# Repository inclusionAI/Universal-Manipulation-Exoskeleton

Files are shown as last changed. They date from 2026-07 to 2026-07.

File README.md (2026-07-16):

<h1> Universal Manipulation Exoskeleton: Learning Compliant Whole-body Policies with Real-time Torque Feedback</h1>
<div align="center">

[Litian Liang](https://www.litianliang.org/)$^{1,\ast}$, [Jingxi Xu](https://jxu.ai/)$^{1,2,\ast}$, [Xinda Qi](https://www.linkedin.com/in/xinda-qi-42467316a)$^{1}$, [Yujun Cai](https://vanoracai.github.io/)$^{1}$, [Houzhu Ding](https://www.linkedin.com/in/houzhuding/)$^{1}$, [Luqi Wang](luqi.w@antgroup.com)$^{1}$, <br>[Zhixin Sun](https://www.linkedin.com/in/zhixin-sun-867335292/)$^{1}$, [Jyh-Herng Chow](https://www.linkedin.com/in/jyh-herng-chow-5831103/)$^{1}$, [Ming Yang](https://users.ece.northwestern.edu/~mya671/)$^{1}$, [Mark Cutkosky](https://me.stanford.edu/people/mark-cutkosky)$^{2}$

$^1$ Ant Group, $^2$ Stanford University<br> 
$^{\ast}$ Equal Contribution

[Website](https://ume-exo.github.io/) | [Paper](https://arxiv.org/pdf/2606.14218) | [Video](https://youtu.be/1x9Pnb9bv7M?si=n2_0ytXx5yQv7l2F) | [X](https://x.com/litian_liang/status/2066541466286215570)



</div>

Universal Manipulation Exoskeleton (UME) is an upper-limb exoskeleton system that provides real-time haptic torque feedback during real robot teleoperation. UME also provide a simple framework to transfer human teleoperation data to autonomous robot policies.

If you find this codebase useful, consider citing:

```bibtex
@article{liang2026universal,
  title={Universal Manipulation Exoskeleton: Learning Compliant Whole-body Policies with Real-time Torque Feedback},
  author={Liang, Litian and Xu, Jingxi and Qi, Xinda and Cai, Yujun and Ding, Houzhu and Wang, Luqi and Sun, Zhixin and Chow, Jyh-Herng and Yang, Ming and Cutkosky, Mark},
  journal={arXiv preprint arXiv:2606.14218},
  year={2026}
}
```

If you have any questions, please contact [Litian Liang](https://www.litianliang.org/) at `l6liang [at] ucsd [dot] edu` or [Jingxi Xu](https://jxu.ai/) at `jxu [at] cs [dot] columbia [dot] edu`.

**Table of Contents**

If you want to start reproducing the hardware and software, you should [get started here](ume/docs/00_starter.md).

 - 🏃‍♀️ [Getting Started](ume/docs/00_starter.md)
 - 🦾 [Universal Manipulation Exoskeleton](ume/docs/01_hardware.md)
   - 🛠️ [Hardware Guide](ume/docs/01_hardware.md)
   - 💻 [Software Guide](ume/docs/02_software.md)
   - 📷 [Data Collection](ume/docs/02_software.md#data-collection)
 - 🤖 [Model Training and Evaluation](ume/docs/02_software.md#model-training)
   - 🚂 [Training](ume/docs/02_software.md#model-training)
   - 📊 [Evaluation](ume/docs/02_software.md#model-evaluation-on-real-robot)
 - 🌍 [Real World Deployment](ume/docs/02_software.md#model-evaluation-on-real-robot)

# Acknowledgements
This work is supported by Ant Group.

We would like to thank Hao Li and Tian-Ao (Teo) Ren from the Stanford BDML Lab for insightful discussions on the mechanical design of UME. We are grateful to Yifan Hou, Zhanyi Sun, and Professor Shuran Song from the Stanford REAL Lab for valuable discussions on autonomous robot experimental design and future applications. We are grateful to Mikael Jorda for feedback on the design of the retargeting algorithm.

We would also like to thank Xiangpeng Miao from Damiao Technology for actuator suggestions and support, Heng Le from X-ARM for assistance with the robotic arms, and Haoxing Guo from Hexfellow Robotics for support with the power caster module.

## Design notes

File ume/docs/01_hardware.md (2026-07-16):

# Hardware Guide

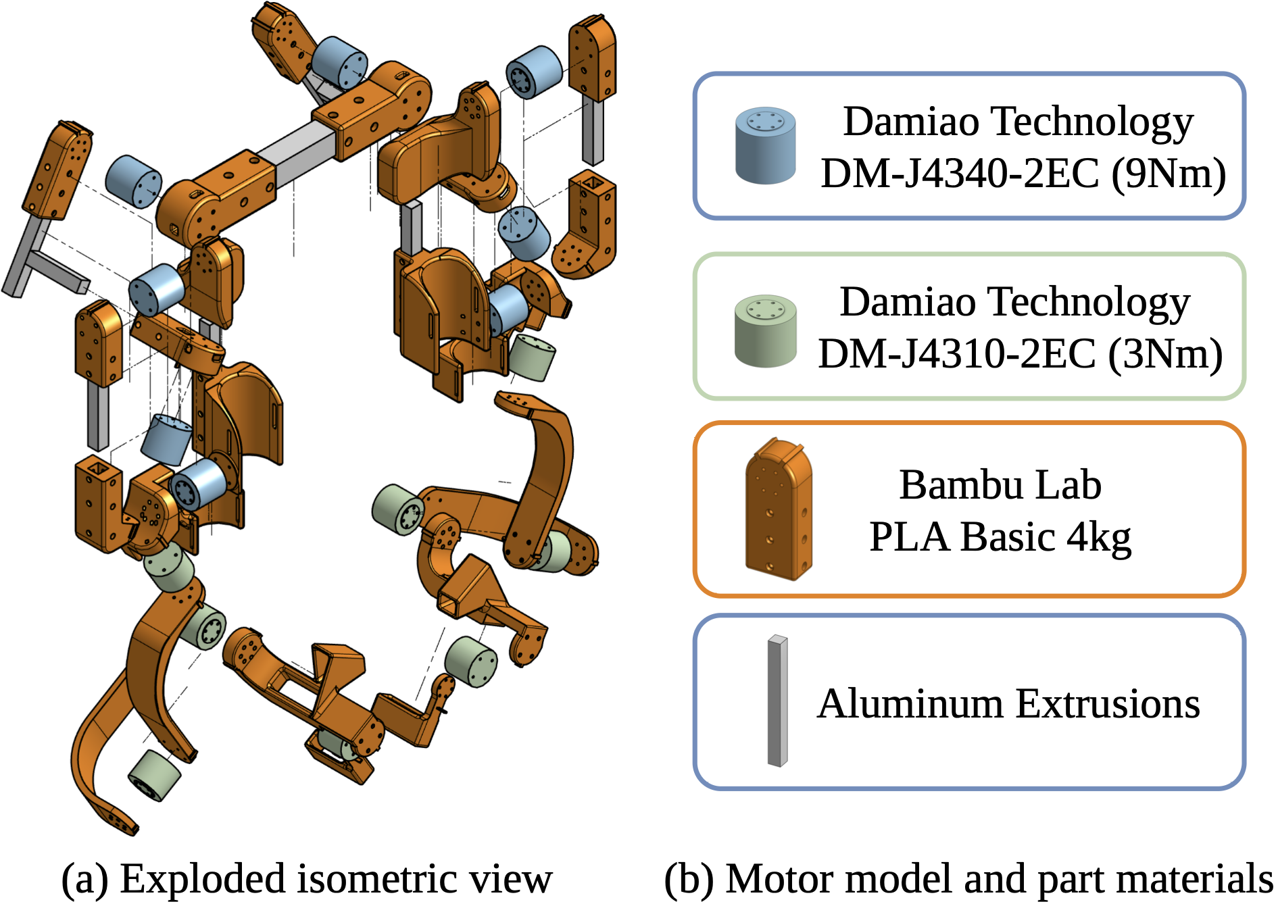
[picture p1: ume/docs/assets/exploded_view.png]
exploded view


## 1. Exoskeleton Parts Preparation:
1. Get the aluminum extrusions, screws, and actuators ready (checkout [paper](https://arxiv.org/pdf/2606.14218) Appendix E.2 for details)
2. Print all the orange parts in PLA basic, checkout [robot model](../robot/ume/v6_imu/models/robot.xml) for part 3D STL files

## 2. Exoskeleton Damiao Actuator Configuration:
Note: For each actuator, it is easier to configure them before installing, although you can still do that through the hole I left for the UART port on the actuator. Here are the steps you need to do to reproduce UME:
1. Download and open [DM tool](https://github.com/dmBots/motor-debugging-tool/tree/7406da26cb56b4c024039f85fde6f7a086ac7e11/Windows/x86_64)
2. Connect the actuator UART port to the [DM UART to USB-C adapter](https://item.taobao.com/item.htm?id=639679565187), then to your PC. Set your DC power supply to 24V and get ready to power on the actuator.

3. Click "open serial port" （打开串口）, it'll turn green and change to "close serial port"（关闭串口）.

4. Power on the actuator. If this status report does not show up, it means the connection is not successful. Try another USB-C cable.
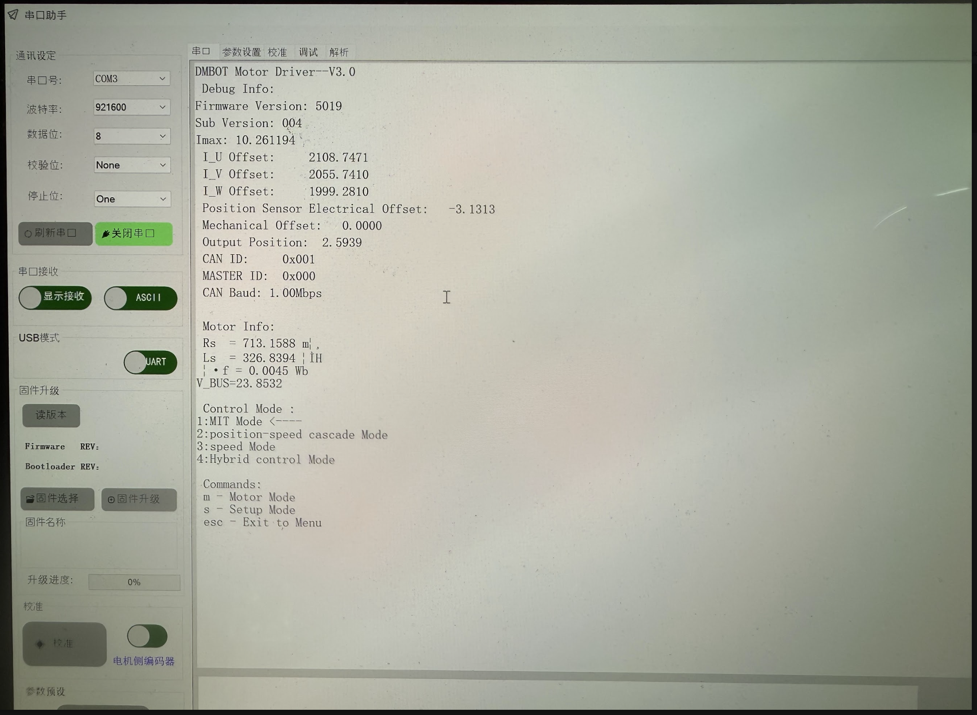
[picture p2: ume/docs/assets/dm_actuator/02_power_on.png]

5. Click Parameter settings（参数设置） in the top selection bar, then click Read parameters（读参数）.
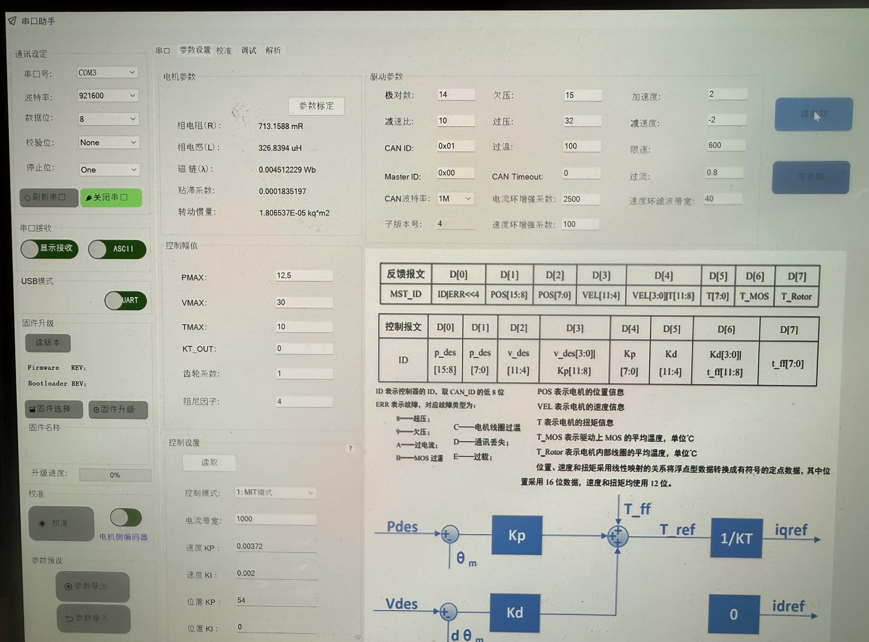
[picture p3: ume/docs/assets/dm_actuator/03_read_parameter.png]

6. For the ith actuator on each arm (from shoulder to gripper 1-8), lets use an example of the shoulder actuator (the 1st)
   1. Set CAN-ID to 0x01 (0x0i for ith)
   2. Set master ID to 0x11 (0x1i for ith)
   3. Click "write parameter"（写参数）. You should see a window pop up saying "parameter write successful"（参数写入成功）
   
7. Go back to the "serial port"（串口） tab in the top selection bar. Set communication frequency to 5Mbps.
   1. Type "s" in the command window below and click send
   2. Type "FCB9" to set the comm frequency to 5Mbps
   3. Power cycle the actuator, you should see a status report that has all the above changes applied. (CAN ID, MASTER ID, CAN BAUD)
   
8. You have successfully configured this actuator. Now repeat the above steps for all the right arm (1-8) and left arm (1-8) actuators.

## 3. Exoskeleton Fabrication & Assembly:

3D printing files checkout: [ume_step folder](../robot/ume/ume_step). Also, please feel free to change the arm length to fit your arm better!

3D printing notes:
1. Use Bambu PLA basic material
2. Slice with triangular pattern and 20% infill
3. It is recommended to use Orange PLA for better strength

I recommend mounting the shoulder onto the table and start assembling from shoulder to wrist. It is also helpful to follow the exploded view above to assemble the exoskeleton. Here are some tips to help you speed up the assembly process

1. For each actuator, use a screw that is ~5mm longer than the depth of screw hole on the PLA parts.
2. For shoulder J2 actuator, first thread the XT30 2+2 cable from J1 through the 2020 aluminum extrusion, then through the hole on the PLA part, then connnect it to J2. This hides the wire in the slot of aluminum extrusion.
3. For other actuators, first assemble and connect the wires. Then rotate the joint to the limit of human range of motion to find the minimum length of wire that needs to be free floating, then tape the wire down to anywhere on the exoskeleton that does not block your movements.
4. Mount the yahboom imu anywhere on the back of exoskeleton with x up y left z forward configuration.

Great! Now you have successfully assembled it. Let's zero all the actuators so they are consistent with software robot model.

## 4. Exoskeleton Actuator Zeroing

1. Print the Zeroing key (a block with a 5mm x 2.5mm x 100mm slot)
2. Find the bump before and after the actuator. Align them and hold them together with the key.
3. Run `ume/robot/ume/v6_bimanual/motor_chain_test.py` but change the `motor_ids` and `motor_types` to the one that you are working on. Then uncomment the `damiao_chain.set_zero()` line and run the code.
4. When running the code, you should see the actuator turn green. And the program outputs 0 for position reading.
5. Now you successfully zeroed this joint. Now repeat for all joints.
6. After you finished all the joints. Check your zeroing with `ume/robot/ume/v6_imu/real_teleop_sim.py`. For safety, make sure to zero out the torque command (change the torque multiplier before the tau_ff_R to 0 here `data_R = ume_R.mit_control(kp=q_zeros, kd=q_zeros, q=q_zeros, dq=q_zeros, tau=1 * tau_ff_R)`) for both arms.

Great! If everything look good, `ume/robot/ume/v6_imu/real_teleop_sim.py` should give correct gravity compensation. Try move the exoskeleton with your hand!

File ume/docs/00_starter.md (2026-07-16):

# Getting Started

Recomended steps to reproduce UME:
1. Clone repo
2. Follow [hardware](01_hardware.md) guide for UME and mobile manipulator assembly
3. Follow [software](02_software.md) guide to make sure all connections are made correctly

After that you should have a working UME!

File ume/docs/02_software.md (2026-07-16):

# Software

Install conda envs using the yaml config files
* `ume/conda_envs/ume_redis.yaml` (robot, teleoperation, inference)
* `ume/conda_envs/ume_torch.yaml` (training, inference)

## 1. Setup

Setup python environment variable.
```
export PYTHONPATH=.
```

### 1.1 Connect to Exoskeleton Yahboom IMU
To use Yahboom IMU, first add yourself to the dialout group to enable serial reading. (I recommend using arduino ide or vscode serial monitor to monitor serial device output)
```
bash ume/robot/ybimu/add_dialout_group.sh
```
If you still can't see serial output, then try disable brltty and reboot.

```
bash ume/robot/ybimu/disable_brltty.sh
```

Now you should be able to see serial output. And run the Yahboom official IMU reader code.
```
conda activate ume_redis
python ume/robot/ybimu/YbImuSerialLib.py
```

### 1.2 Connect to Hexfellow PCW-25 and Damiao Motors
Enable can, (make sure mobile base is on CAN0&1, arm on CAN2&3, exo on CAN4&5)
```
bash ume/robot/mobile_openarm/enable_can.sh
```
You can run this script to check which device is connected to which CAN. This script will make the damiao motors led light go green.
```
python ume/robot/ume/v6_bimanual/motor_chain_test.py
```

### 1.3 Hexfellow PCW-25 Robot Wheel Zeroing
1. connect a xbox gamepad to the computer
2. run `ume/robot/mobile_openarm/hexfellow_base_xbox_teleop.py` to start teleoperating the mobile base
3. adjust `rev_offset` in the `get_actual_position_rad` of `ume/robot/mobile_openarm/ hexfellow_base_imu_teleop_redis.py` base on your wheel mounting orientation
4. adjust `rev_offset` until the robot moves in the correct orientation (pitch corresponds to robot local frame x direction, roll is y, and yaw is theta)

## 2. Gravity compensation Demo
To help make sure UME is reproduced correctly, you can run the gravity compensation demo to check if the torque value is correct. 

**First time reproduction note**: it is safer to enable the mujoco visualization window, and multiply 0.5 to the gravity compensation torque.
```
python ume/robot/ume/v6_imu/real_teleop_sim.py
```

## 3. Teleop OpenArm

Run the arm teleoperation demo. This helps you make sure both openarm and UME are configured correctly.
* press `b` to slowly move the arm to the desired position
* press ` to engage torque-feedback teleoperation
```
process-compose -f ume/robot/ume/v6_imu/teleop_openarm.yaml
```

Run the mobile teleoperation demo. Tilt your body to control the mobile base, same keys as above to start the arm teleoperation.
```
process-compose -f ume/robot/ume/v6_imu/teleop_openarm_mobile.yaml
```

Now UME and Hexfellow OpenArm mobile manipulator are all working properly. Let's collect some data with it.

# Data Collection

Run the data collection script.
```
process-compose -f ume/robot/mobile_openarm/collect_data.yaml
```
You should see the live camera preview show up, and a window of a pure green image to indicate recording is not started (red if recording).
* press `b` to slowly move the arm to the desired position
* press ` to engage torque-feedback teleoperation
* press `u` to start recording
* press `q` to stop recording

data collected should be in the `data` folder in the format of
```
data
|--collecting
   |--YYYY_MM_DD_HH_MM_SS_TIMEZONE
      |--low_dim_npys
      |--camera_head.mp4
      |--camera_wrist_left.mp4
      |--camera_wrist_right.mp4
```

# Model Training
Train a UME model:
```
python ume/learning/mobile_openarm_ume/act_train_ume.py
```
Train No-Torque baseline model:
```
python ume/learning/mobile_openarm_no_torque/act_train_no_torque.py
```
Train UMI baseline model:
```
python ume/learning/mobile_openarm_umi/act_train_umi.py
```

# Model Evaluation on Real Robot

## 1. Setup
1. setup model ckpt path at `ume/learning/mobile_openarm_ume/model_inference_worker.py`
2. setup initial arm configuration path at `ume/learning/mobile_openarm/eval_openarm_controller.py`

## 2. Eval
Evaluate a UME model:
```
process-compose -f ume/learning/mobile_openarm_ume/eval_mobile_openarm.yaml
```
You can use similar commands to evaluate No-Torque and UMI baseline models.

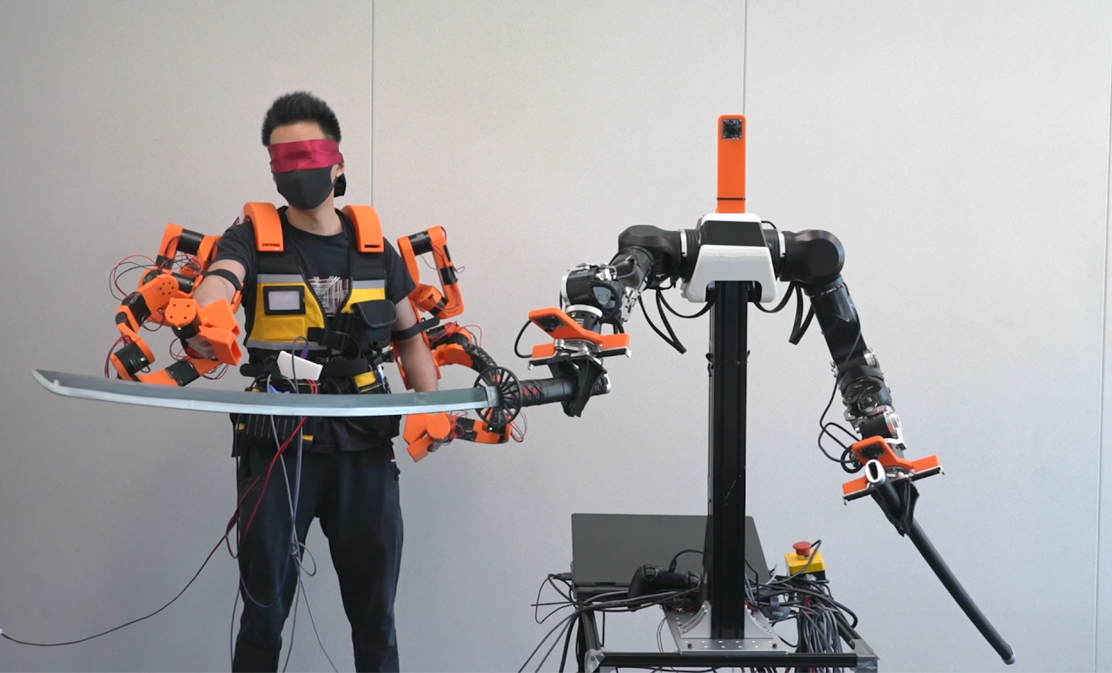
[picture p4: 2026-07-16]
ume/docs/assets/unsheathe_final.png

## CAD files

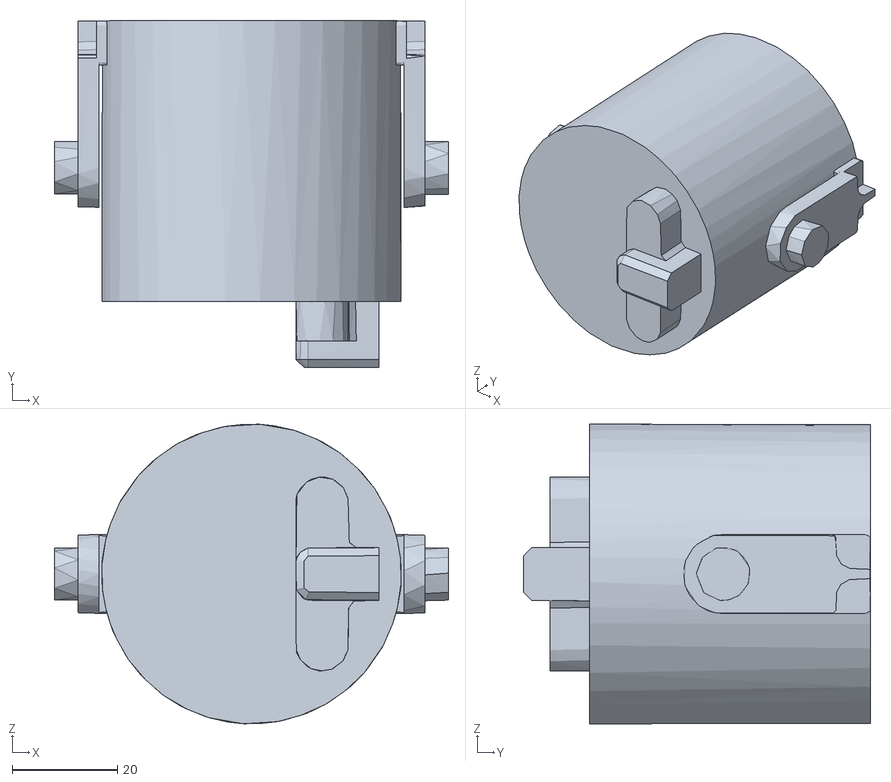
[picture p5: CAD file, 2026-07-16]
ume/robot/openarm1/models/meshes/collision/arm/link6.stl
75.0 x 66.0 x 57.0

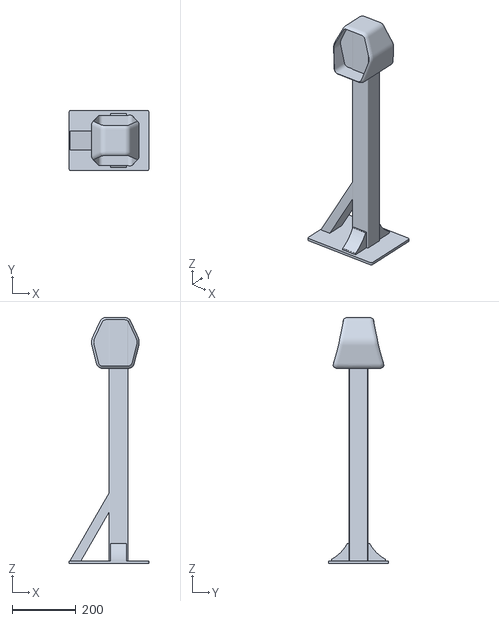
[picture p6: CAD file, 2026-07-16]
ume/robot/openarm1/models/meshes/collision/body/body_link0.stl
250.0 x 190.0 x 773.0

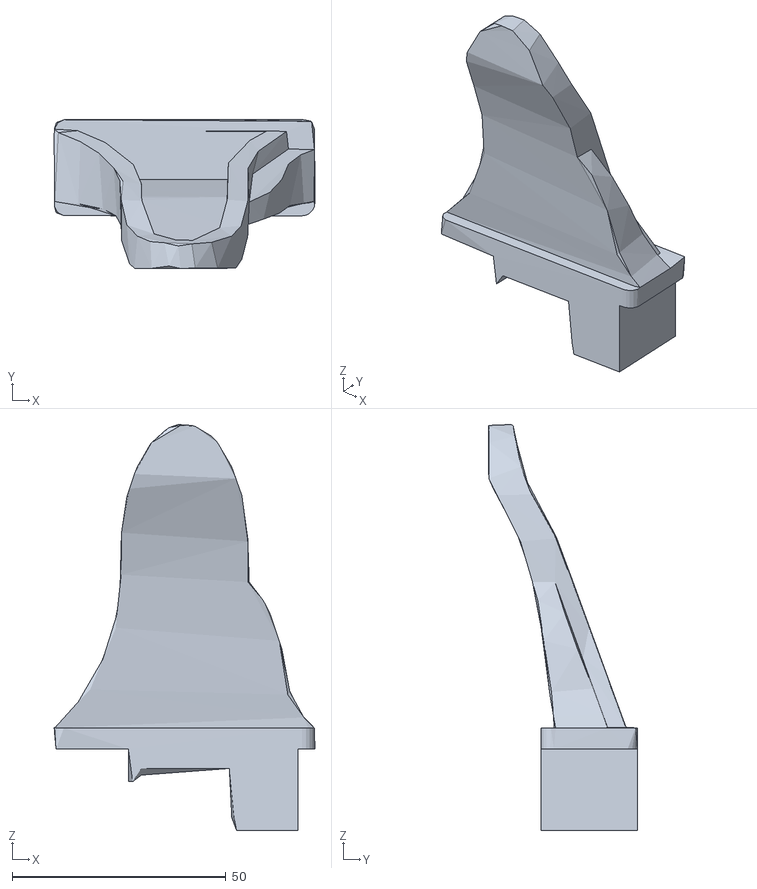
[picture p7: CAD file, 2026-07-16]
ume/robot/openarm1/models/meshes/collision/gripper/finger.stl
61.0 x 34.8 x 94.9

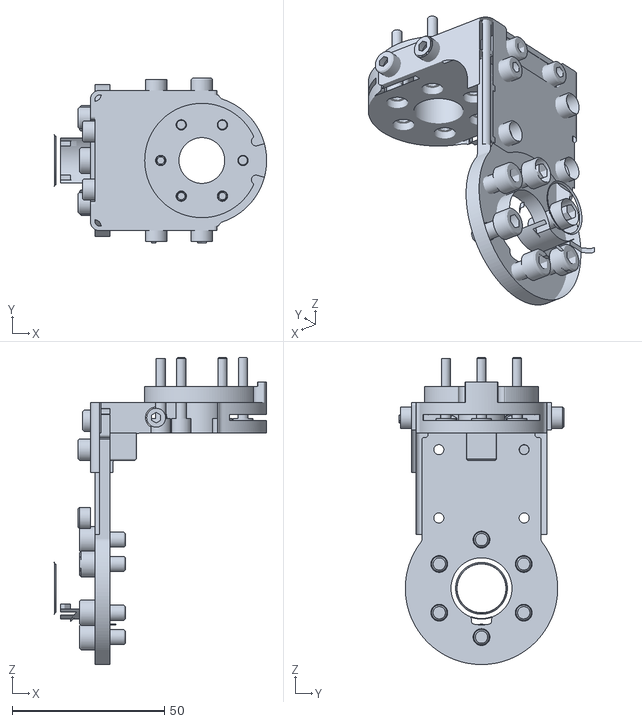
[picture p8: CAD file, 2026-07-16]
ume/robot/openarm1/models/meshes/visual/arm/link2_1.obj
69.7 x 54.0 x 100.7

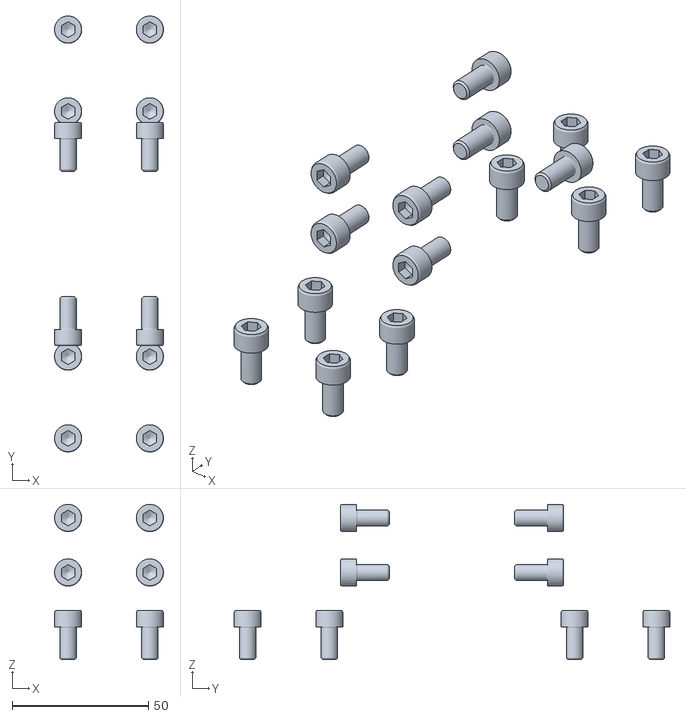
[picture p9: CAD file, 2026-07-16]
ume/robot/openarm1/models/meshes/visual/body/body_link0_2.obj
40.0 x 160.0 x 57.0

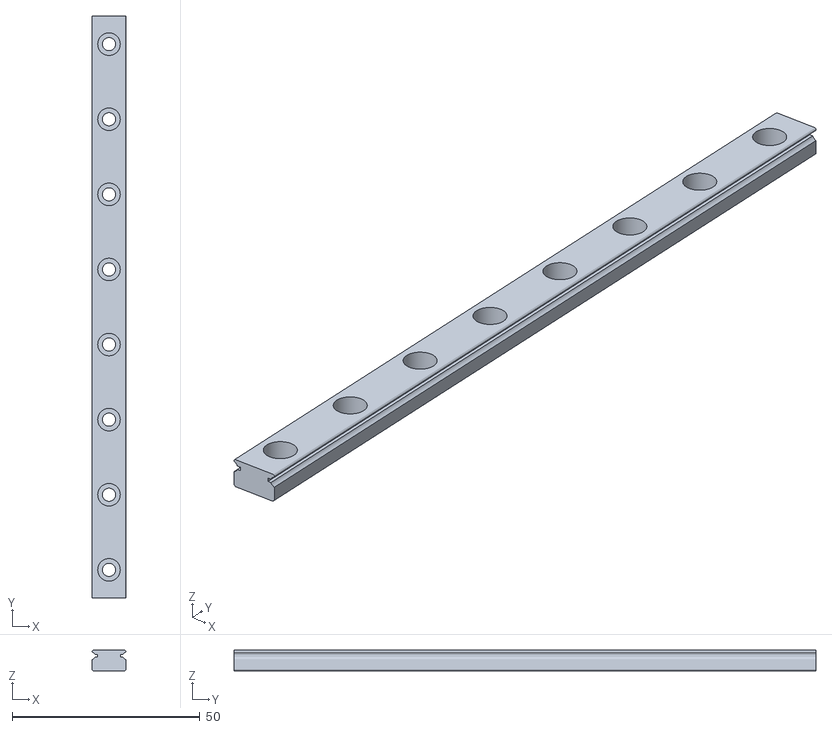
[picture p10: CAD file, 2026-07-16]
ume/robot/openarm1/models/meshes/visual/gripper/hand_0.obj
9.00 x 155.0 x 5.50

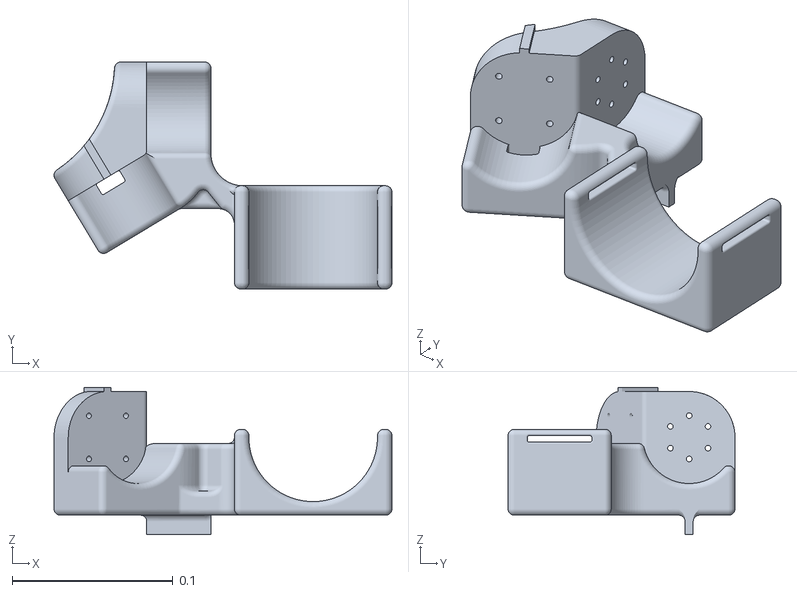
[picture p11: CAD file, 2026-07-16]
ume/robot/ume/v6_imu/models/assets/v6_j4_j5_r.stl
0.21 x 0.141 x 0.0915

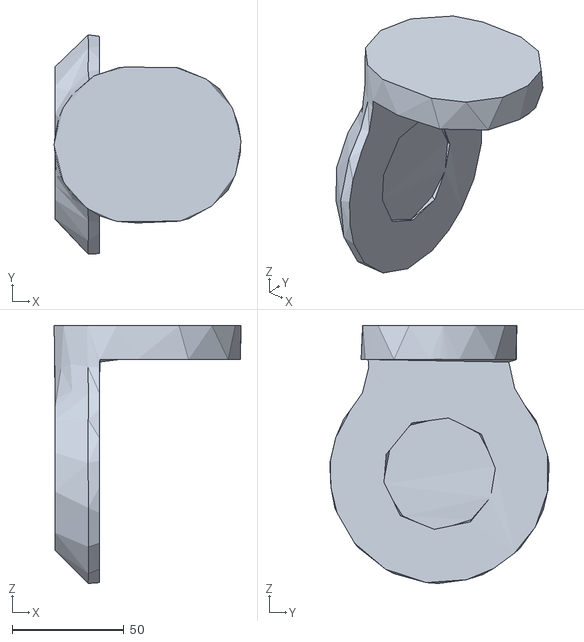
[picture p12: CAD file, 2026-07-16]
ume/robot/openarm1/models/meshes/collision/arm/link2.stl
83.7 x 98.3 x 115.6

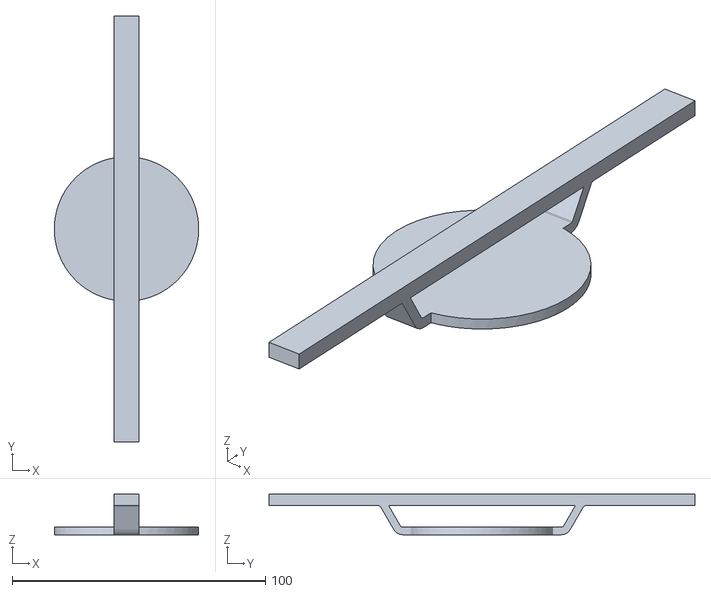
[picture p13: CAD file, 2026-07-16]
ume/robot/openarm1/models/meshes/collision/gripper/hand.stl
57.0 x 168.1 x 16.0

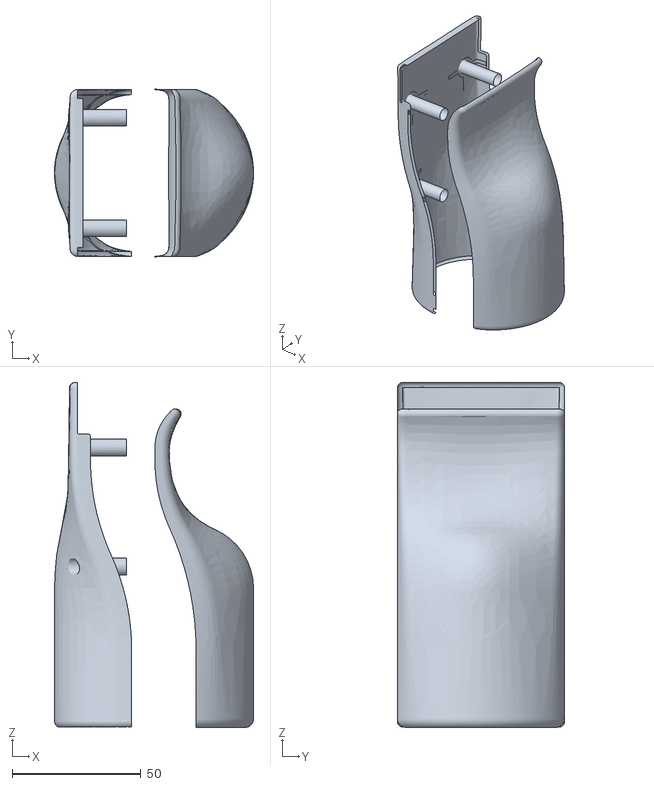
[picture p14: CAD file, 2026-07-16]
ume/robot/openarm1/models/meshes/visual/arm/link3_1.obj
77.3 x 65.0 x 134.0

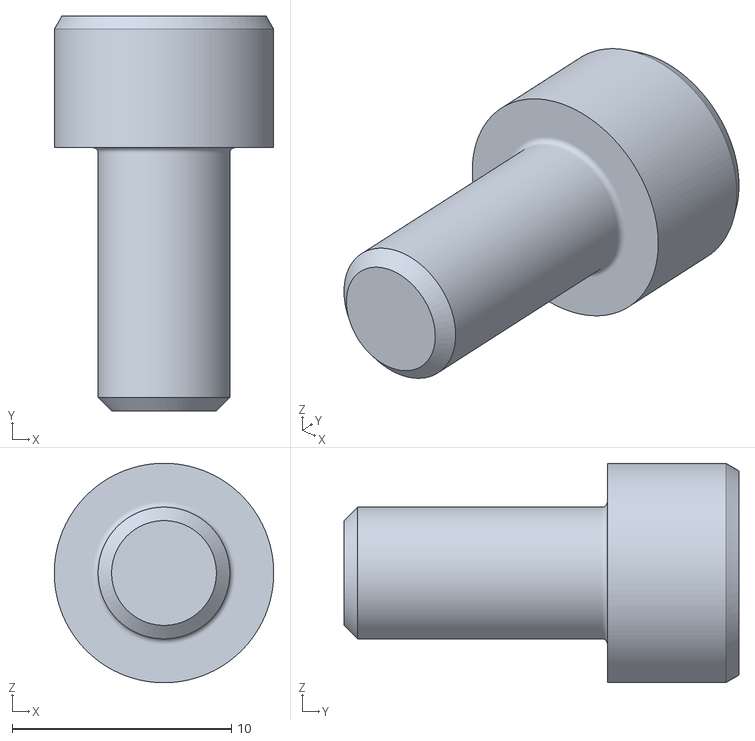
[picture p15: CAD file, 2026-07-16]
ume/robot/openarm1/models/meshes/visual/body/body_link0_0.obj
10.0 x 18.0 x 10.00

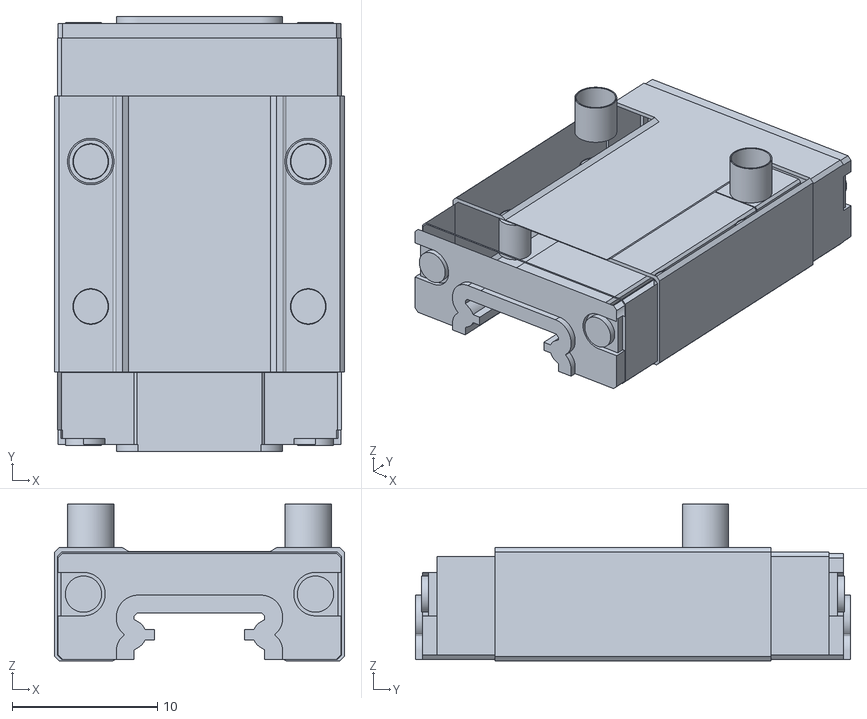
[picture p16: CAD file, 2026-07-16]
ume/robot/openarm1/models/meshes/visual/gripper/finger_0.obj
20.0 x 30.0 x 10.8

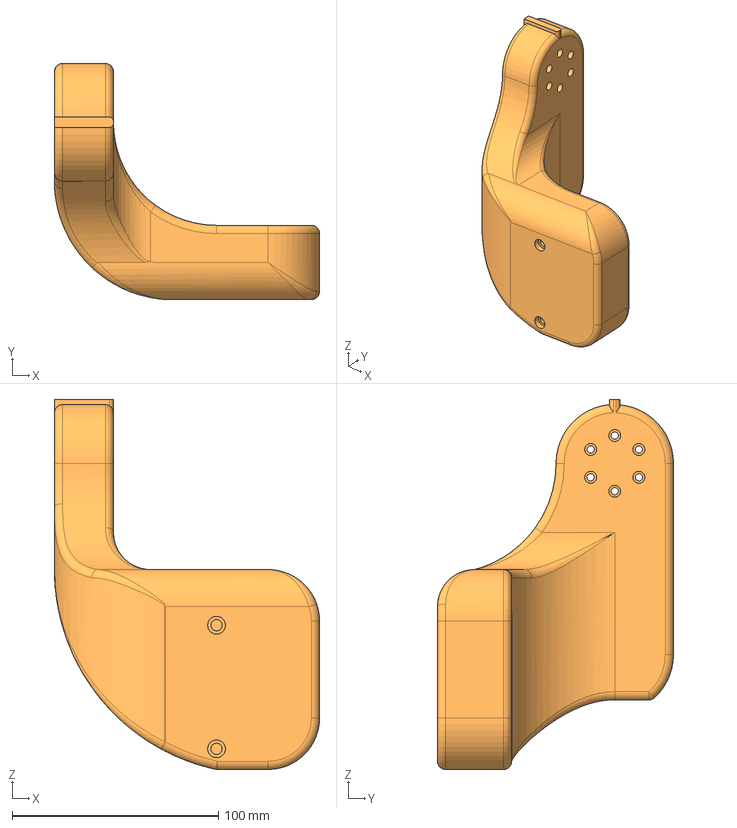
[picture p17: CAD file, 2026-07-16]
ume/robot/ume/ume_step/ume_v6_bimanual - v6_J3_2020_L.step
128.7 x 114.5 x 179.5 mm

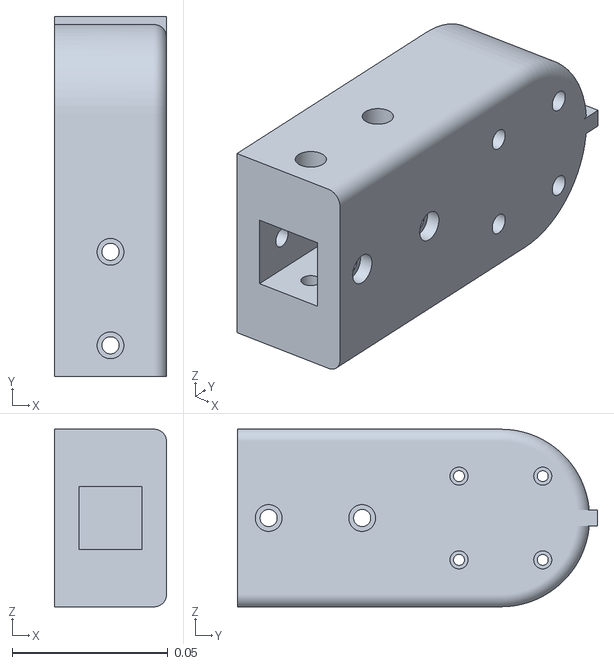
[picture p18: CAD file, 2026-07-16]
ume/robot/ume/v6_bimanual/models/assets/v6_j2_20.stl
0.036 x 0.116 x 0.057

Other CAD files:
ume/robot/ume/v6_imu/models/assets/4040_ybimu.stl
ume/robot/openarm1/models/meshes/collision/arm/link0.stl
ume/robot/openarm1/models/meshes/visual/arm/link5_0.obj
ume/robot/openarm1/models/meshes/visual/body/body_link0_1.obj
ume/robot/openarm1/models/meshes/collision/arm/link1.stl
ume/robot/openarm1/models/meshes/collision/arm/link3.stl
ume/robot/openarm1/models/meshes/collision/arm/link4.stl
ume/robot/openarm1/models/meshes/collision/arm/link5.stl
ume/robot/openarm1/models/meshes/collision/arm/link7.stl
ume/robot/openarm1/models/meshes/visual/arm/link0_0.obj
ume/robot/openarm1/models/meshes/visual/arm/link0_1.obj
ume/robot/openarm1/models/meshes/visual/arm/link1_0.obj
ume/robot/openarm1/models/meshes/visual/arm/link1_1.obj
ume/robot/openarm1/models/meshes/visual/arm/link1_2.obj
ume/robot/openarm1/models/meshes/visual/arm/link1_3.obj
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

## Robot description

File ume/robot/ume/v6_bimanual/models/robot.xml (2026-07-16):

<?xml version="1.0" ?>
<mujoco model="models">
  <compiler angle="radian" meshdir="assets" autolimits="true"/>
  <default>
    <default class="models">
      <joint frictionloss="0.1" armature="0.005"/>
      <position kp="50" dampratio="1"/>
      <default class="visual">
        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
      </default>
      <default class="collision">
        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
      </default>
    </default>
  </default>
  <worldbody>
    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
    <body name="v5_4040_j1" pos="0 0 0" quat="1 0 0 0" childclass="models">
      <inertial pos="-0.00725532 0.0615 -0" mass="1.044" fullinertia="0.0381441 0.000626549 0.0381676 -0 -0 6e-11"/>
      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
      <body name="v6_j1_20" pos="-0.0383 -0.1385 0" quat="0.183013 0.683013 -0.183013 -0.683013">
        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
        <joint axis="0 0 1" name="RJ1" type="hinge"/>
        <inertial pos="0.150386 -5.99e-10 -0.0862657" mass="0.64749" fullinertia="0.0032465 0.00514141 0.00215547 6e-12 0.00180143 1.8e-11"/>
        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
        <body name="v6_20_j3" pos="0.2065 -0 -0.139098" quat="0.5 0.5 0.5 0.5">
          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
          <joint axis="0 0 1" name="RJ2" type="hinge"/>
          <inertial pos="0.0816108 2.273e-09 -0.108365" mass="0.6629" fullinertia="0.00347714 0.00399968 0.000810527 1.64e-10 0.00105864 -1.66e-10"/>
          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
          <body name="v6_j3_2020_r" pos="0.0680103 -0 -0.175034" quat="0.353553 0.612372 -0.612372 -0.353553">
            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
            <joint axis="0 0 1" name="RJ3" type="hinge"/>
            <inertial pos="-0.0212538 0.197218 0.0388781" mass="0.86248" fullinertia="0.00735386 0.00260883 0.00681043 -0.00104227 0.000890554 0.000819778"/>
            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
            <body name="v6_j4_j5_r" pos="0.00787981 0.26 -0.025968" quat="0 0.707107 -0.707107 -0">
              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
              <joint axis="0 0 1" name="RJ4" type="hinge"/>
              <inertial pos="-0.054697 0.00944171 -0.00245461" mass="0.49139" fullinertia="0.00105657 0.00119188 0.000538644 -2.97344e-05 -0.000120659 0.000177465"/>
              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
              <body name="v6_wrist_j5_j6" pos="-0.0825226 -0 0.000785249" quat="0 -0.870373 0 0.492393">
                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
                <joint axis="0 0 1" name="RJ5" type="hinge"/>
                <inertial pos="-0.145145 7.46224e-05 0.168843" mass="0.4484" fullinertia="0.00261478 0.00340573 0.00098092 -2.29433e-06 0.00132169 3.71339e-06"/>
                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
                <body name="v5_wrist_j6_j7" pos="-0.1919 0 0.212" quat="0 -0.707107 -0 0.707107">
                  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
                  <joint axis="0 0 1" name="RJ6" type="hinge"/>
                  <inertial pos="-0 0.0975631 -0.161926" mass="0.407" fullinertia="0.00180585 0.00164708 0.000326757 0 -0 0.000247612"/>
                  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
                  <body name="v5_wrist_j7_leader_gripper_r" pos="-0 0.0751 -0.191" quat="0.5 0.5 -0.5 0.5">
                    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
                    <joint axis="0 0 1" name="RJ7" type="hinge"/>
                    <inertial pos="-0.00205487 0.0647313 0.154012" mass="0.4573" fullinertia="0.00200291 0.00193779 0.000443531 -3.45159e-05 2.74273e-06 -0.000439089"/>
                    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
                    <body name="v5_j8_4finger" pos="0 0.075 0.1641" quat="0 -0.707107 -0.707107 -0">
                      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
                      <joint axis="0 0 1" name="RJ8" type="hinge"/>
                      <inertial pos="0.0582262 -2.729e-09 0.031412" mass="0.0384" fullinertia="3.92746e-05 6.14789e-05 2.96973e-05 -1e-12 -1.19931e-05 2e-12"/>
                      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
                    </body>
                  </body>
                </body>
              </body>
            </body>
          </body>
        </body>
      </body>
      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
      <body name="dm_j4340_2ec" pos="-0.0383 0.2615 -0" quat="0.183013 -0.683013 -0.183013 0.683013">
        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
        <joint axis="0 0 1" name="LJ1" type="hinge"/>
        <inertial pos="0.150386 -5.99e-10 -0.0862657" mass="0.64749" fullinertia="0.0032465 0.00514141 0.00215547 6e-12 0.00180143 1.8e-11"/>
        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
        <body name="dm_j4340_2ec_2" pos="0.2065 0 -0.139098" quat="0.5 -0.5 0.5 -0.5">
          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
          <joint axis="0 0 1" name="LJ2" type="hinge"/>
          <inertial pos="0.0816108 2.273e-09 -0.108365" mass="0.6629" fullinertia="0.00347714 0.00399968 0.000810527 1.64e-10 0.00105864 -1.66e-10"/>
          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
          <body name="v6_j3_2020_l" pos="0.0680103 -0 -0.175034" quat="0.353553 -0.612372 -0.612372 0.353553">
            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
            <joint axis="0 0 1" name="LJ3" type="hinge"/>
            <inertial pos="-0.0211335 -0.197218 0.0388781" mass="0.86248" fullinertia="0.00735383 0.00260882 0.0068104 0.00104226 0.00089055 -0.00081978"/>
            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
            <body name="v6_j4_j5_l" pos="0.008 -0.26 -0.025968" quat="0 0.707107 0.707107 0">
              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
              <joint axis="0 0 1" name="LJ4" type="hinge"/>
              <inertial pos="-0.054697 -0.0094417 -0.00245459" mass="0.49139" fullinertia="0.00105657 0.00119187 0.000538643 2.97343e-05 -0.000120659 -0.000177465"/>
              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
              <body name="v6_wrist_j5_j6_2" pos="-0.0825226 -0 0.000785249" quat="0 -0.870373 0 0.492393">
                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
                <joint axis="0 0 1" name="LJ5" type="hinge"/>
                <inertial pos="-0.145035 -0.000119401 0.168953" mass="0.4484" fullinertia="0.00260463 0.00340197 0.000987304 3.35036e-06 0.00132357 -5.25689e-06"/>
                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
                <body name="v5_wrist_j6_j7_2" pos="-0.1919 -0 0.212" quat="0.707107 0 -0.707107 -0">
                  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
                  <joint axis="0 0 1" name="LJ6" type="hinge"/>
                  <inertial pos="-0 0.0975631 -0.161926" mass="0.407" fullinertia="0.00180585 0.00164708 0.000326757 0 -0 0.000247612"/>
                  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
                  <body name="dm_j4310_2ec" pos="-0 0.0751 -0.191" quat="0.5 0.5 0.5 -0.5">
                    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
                    <joint axis="0 0 1" name="LJ7" type="hinge"/>
                    <inertial pos="0.00205488 0.0647314 0.154012" mass="0.4573" fullinertia="0.00200291 0.00193779 0.000443531 3.45159e-05 -2.7424e-06 -0.000439089"/>
                    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
                    <body name="v5_j8_4finger_2" pos="0 0.075 0.1641" quat="0 -0.707107 -0.707107 -0">
                      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
                      <joint axis="0 0 1" name="LJ8" type="hinge"/>
                      <inertial pos="0.0582262 -2.729e-09 0.031412" mass="0.0384" fullinertia="3.92746e-05 6.14789e-05 2.96973e-05 -1e-12 -1.19931e-05 2e-12"/>
                      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
                    </body>
                  </body>
                </body>
              </body>
            </body>
          </body>
        </body>
      </body>
    </body>
  </worldbody>
  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
  <actuator>
    <position class="models" name="RJ1" joint="RJ1"/>
    <position class="models" name="RJ2" joint="RJ2"/>
    <position class="models" name="RJ3" joint="RJ3"/>
    <position class="models" name="RJ4" joint="RJ4"/>
    <position class="models" name="RJ5" joint="RJ5"/>
    <position class="models" name="RJ6" joint="RJ6"/>
    <position class="models" name="RJ7" joint="RJ7"/>
    <position class="models" name="RJ8" joint="RJ8"/>
    <position class="models" name="LJ1" joint="LJ1"/>
    <position class="models" name="LJ2" joint="LJ2"/>
    <position class="models" name="LJ3" joint="LJ3"/>
    <position class="models" name="LJ4" joint="LJ4"/>
    <position class="models" name="LJ5" joint="LJ5"/>
    <position class="models" name="LJ6" joint="LJ6"/>
    <position class="models" name="LJ7" joint="LJ7"/>
    <position class="models" name="LJ8" joint="LJ8"/>
  </actuator>
  <equality/>
</mujoco>

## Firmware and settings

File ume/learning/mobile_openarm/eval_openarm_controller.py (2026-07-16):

import time

import can
import numpy as np

import typer
from ume.redis_client import RedisClient
from ume.tools.precise_sleep import FrequencyRegulator

from ume.robot.openarm1.solver import OpenArm1Solver
from ume.tools.keycounter import KeystrokeCounter, Key, KeyCode
from ume.tools.pose_interp import get_interp1d
from ume.tools.npy_read_write import save_dict_to_npy, load_dict_from_npy

FOLLOWER_KP = np.array([240.0, 240.0, 240.0, 240.0, 24.0, 31.0, 25.0, 16.0])
FOLLOWER_KD = np.array([3.0, 3.0, 3.0, 3.0, 0.2, 0.2, 0.2, 0.2])

def main(
    redis_host: str = "localhost",
    redis_port: int = 6379,
    follower_left: str = "follower_left",
    follower_right: str = "follower_right",
    frequency_hz: float = 2000,
    initial_arm_state_reference_episode_lowdim_path: str = "data/initial_pose_default/low_dim_npys",
    model_inference_worker_name: str = "model_inference",
    chunk_renew_every_s: float = 2.0,
    name: str = "openarm_controller",
    stitch_duration: float = 0.45
):
    
    client = RedisClient(host=redis_host, port=redis_port)
    reg = FrequencyRegulator(frequency=frequency_hz)
    solver = OpenArm1Solver()
    q_zeros = np.zeros(8)
    
    reference_episode = load_dict_from_npy(initial_arm_state_reference_episode_lowdim_path)
    reference_qpos_L = reference_episode[f"openarm_follower_left_state:actual_angle_rad"][0]
    reference_qpos_R = reference_episode[f"openarm_follower_right_state:actual_angle_rad"][0]
    print(f"Reference initial qpos_L: {reference_qpos_L.shape}, qpos_R: {reference_qpos_R.shape}")
    
    eval_state = "idle" # idle, enabling, evaluating
    qpos_interp_L = None
    qpos_interp_R = None
    
    with KeystrokeCounter() as key_counter:
    
        iter_idx = 0
        while True:
            data_batch = client.stream_get_batch(
                {
                    f"{follower_left}_state:actual_angle_rad": np.ndarray,
                    f"{follower_left}_state:actual_velocity_radps": np.ndarray,
                    f"{follower_left}_state:actual_torque_nm": np.ndarray,

                    f"{follower_right}_state:actual_angle_rad": np.ndarray,
                    f"{follower_right}_state:actual_velocity_radps": np.ndarray,
                    f"{follower_right}_state:actual_torque_nm": np.ndarray,
                    
                    f"{model_inference_worker_name}:action_timestamp": np.ndarray,
                    f"{model_inference_worker_name}:action_desired_qpos_left": np.ndarray,
                    f"{model_inference_worker_name}:action_desired_qpos_right": np.ndarray
                }
            )
            
            # model inference state
            model_action_timestamp = data_batch[f"{model_inference_worker_name}:action_timestamp"]
            model_desired_qpos_left = data_batch[f"{model_inference_worker_name}:action_desired_qpos_left"]
            model_desired_qpos_right = data_batch[f"{model_inference_worker_name}:action_desired_qpos_right"]
            
            # robot state
            qpos_L = data_batch[f"{follower_left}_state:actual_angle_rad"]
            qpos_R = data_batch[f"{follower_right}_state:actual_angle_rad"]
            sim_qpos_L = np.concatenate([qpos_L[:7], [0, 0]])
            sim_qpos_R = np.concatenate([qpos_R[:7], [0, 0]])
            sim_qpos = np.concatenate([sim_qpos_L, sim_qpos_R])
            
            qvel_L = data_batch[f"{follower_left}_state:actual_velocity_radps"]
            qvel_R = data_batch[f"{follower_right}_state:actual_velocity_radps"]
            sim_qvel_L = np.concatenate([qvel_L[:7], [0, 0]])
            sim_qvel_R = np.concatenate([qvel_R[:7], [0, 0]])
            sim_qvel = np.concatenate([sim_qvel_L, sim_qvel_R])
            
            solver.forward_kinematics(sim_qpos)
            
            desired_qacc = np.zeros_like(sim_qpos)
            tau = solver.get_gravity_compensation_torques(sim_qpos, sim_qvel, desired_qacc)
            desired_tau_L = np.concatenate([tau[0:7], [0.0]])
            desired_tau_R = np.concatenate([tau[8:15], [0.0]])
            
            # compute interaction torque
            tau_actual_L = data_batch[f"{follower_left}_state:actual_torque_nm"]
            tau_actual_R = data_batch[f"{follower_right}_state:actual_torque_nm"]
            tau_interaction_L = tau_actual_L - desired_tau_L
            tau_interaction_R = tau_actual_R - desired_tau_R
            
            desired_timestamp = time.time()
            for press_events in key_counter.get_press_events():
                if press_events == KeyCode(char='b'):
                    eval_state = "enabling"
                    enabling_duration = 1.5
                    enabling_timestamps = np.array([desired_timestamp, desired_timestamp + enabling_duration])
                    qpos_L_start_end = np.stack([qpos_L, reference_qpos_L], axis=0)
                    qpos_R_start_end = np.stack([qpos_R, reference_qpos_R], axis=0)
                    qpos_interp_L = get_interp1d(enabling_timestamps, qpos_L_start_end)
                    qpos_interp_R = get_interp1d(enabling_timestamps, qpos_R_start_end)
                    print("Enabling... Interpolating from current position to reference initial position over 5 seconds.")
                elif press_events == KeyCode(char='`'):
                    if model_action_timestamp is not None:
                        eval_state = "evaluating"
                        qpos_interp_L = get_interp1d(model_action_timestamp, model_desired_qpos_left)
                        qpos_interp_R = get_interp1d(model_action_timestamp, model_desired_qpos_right)
                        print("Evaluating... Interpolating desired qpos from model inference.")
                    else:
                        print("No model inference data received yet. Cannot start evaluating.")
                elif press_events == KeyCode(char='s'):
                    eval_state = "idle"
                    qpos_interp_L = None
                    qpos_interp_R = None
                    print("Stopping. Returning to idle state.")
            
            if eval_state == "evaluating" and t_now > qpos_interp_L.x[0] + chunk_renew_every_s + stitch_duration:
                # if we are evaluating and close to the end of the model predicted trajectory
                # recompute the interpolator with latest model output
                # qpos_interp_L = get_interp1d(model_action_timestamp, model_desired_qpos_left)
                # qpos_interp_R = get_interp1d(model_action_timestamp, model_desired_qpos_right)
                # last interp end time and qpos
                last_interp_end_time = qpos_interp_L.x[0] + chunk_renew_every_s + stitch_duration
                last_interp_end_qpos_L = qpos_interp_L(last_interp_end_time)
                last_interp_end_qpos_R = qpos_interp_R(last_interp_end_time)
                
                # Litian HACK: stich 2 trajectories
                # stitch_duration = 0.0
                # qpos_interp_L = get_interp1d(model_action_timestamp, model_desired_qpos_left)
                # qpos_interp_R = get_interp1d(model_action_timestamp, model_desired_qpos_right)
                stitched_model_action_timestamp = np.concatenate([[last_interp_end_time], model_action_timestamp + stitch_duration])
                stitched_model_desired_qpos_left = np.concatenate([last_interp_end_qpos_L[None, :], model_desired_qpos_left], axis=0)
                stitched_model_desired_qpos_right = np.concatenate([last_interp_end_qpos_R[None, :], model_desired_qpos_right], axis=0)
                
                qpos_interp_L = get_interp1d(stitched_model_action_timestamp, stitched_model_desired_qpos_left)
                qpos_interp_R = get_interp1d(stitched_model_action_timestamp, stitched_model_desired_qpos_right)
                print("Recomputing qpos interpolators with latest model inference output.")
                
            
            # send command that is appropriate for the current eval_state
            if eval_state == "idle":
                command_batch = {
                    f"{follower_left}_mit_command:timestamp": desired_timestamp,
                    f"{follower_left}_mit_command:kp" : q_zeros,
                    f"{follower_left}_mit_command:kd" : q_zeros,
                    f"{follower_left}_mit_command:q"  : qpos_L,
                    f"{follower_left}_mit_command:dq" : q_zeros,
                    f"{follower_left}_mit_command:tau": desired_tau_L,

                    f"{follower_right}_mit_command:timestamp": desired_timestamp,
                    f"{follower_right}_mit_command:kp" : q_zeros,
                    f"{follower_right}_mit_command:kd" : q_zeros,
                    f"{follower_right}_mit_command:q"  : qpos_R,
                    f"{follower_right}_mit_command:dq" : q_zeros,
                    f"{follower_right}_mit_command:tau": desired_tau_R,
                    
                    f"{name}_state:timestamp": desired_timestamp,
                    f"{name}_state:tau_interaction_L": tau_interaction_L,
                    f"{name}_state:tau_interaction_R": tau_interaction_R,
                }
            elif eval_state == "enabling" or eval_state == "evaluating":
                t_now = time.time()
                desired_qpos_L = qpos_interp_L(t_now)
                desired_qpos_R = qpos_interp_R(t_now)
                print(f"{time.time():.4f} Desired qpos delta (deg): Left max abs {np.rad2deg(np.abs(desired_qpos_L - qpos_L)).max():.2f}, Right max abs {np.rad2deg(np.abs(desired_qpos_R - qpos_R)).max():.2f}")
                command_batch = {
                    f"{follower_left}_mit_command:timestamp": desired_timestamp,
                    f"{follower_left}_mit_command:kp" : FOLLOWER_KP,
                    f"{follower_left}_mit_command:kd" : FOLLOWER_KD,
                    f"{follower_left}_mit_command:q"  : desired_qpos_L,
                    f"{follower_left}_mit_command:dq" : q_zeros,
                    f"{follower_left}_mit_command:tau": desired_tau_L,
                    
                    f"{follower_right}_mit_command:timestamp": desired_timestamp,
                    f"{follower_right}_mit_command:kp" : FOLLOWER_KP,
                    f"{follower_right}_mit_command:kd" : FOLLOWER_KD,
                    f"{follower_right}_mit_command:q"  : desired_qpos_R,
                    f"{follower_right}_mit_command:dq" : q_zeros,
                    f"{follower_right}_mit_command:tau": desired_tau_R,
                    
                    f"{name}_state:timestamp": desired_timestamp,
                    f"{name}_state:tau_interaction_L": tau_interaction_L,
                    f"{name}_state:tau_interaction_R": tau_interaction_R,
                }
            else:
                raise ValueError(f"Unknown eval_state: {eval_state}")

            command_batch_maxlen = {key: int(frequency_hz * 10) for key in command_batch.keys()}  # Litian HACK: 10 seconds
            client.stream_add_batch(command_batch, command_batch_maxlen)

            reg.sleep(verbose=True, verbose_interval=1, verbose_prefix=f"openarm controller")
            iter_idx += 1
            
            if iter_idx == 1:
                print("openarm controller ready")


if __name__ == "__main__":
    typer.run(main)

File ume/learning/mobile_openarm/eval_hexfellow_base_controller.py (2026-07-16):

import numpy as np
import time
import canopen
from ume.hexfellow_chain import HexFellowChain
from ume.robot.mobile_base.power_caster_base import PowerCasterBaseKinematics
from ume.robot.mobile_openarm.hexfellow_base_imu_teleop_redis import HexFellowBaseController

import typer
from ume.tools.pose_interp import get_interp1d
from ume.tools.precise_sleep import FrequencyRegulator
from ume.xbox import XboxController
from ume.tools.keycounter import KeystrokeCounter, Key, KeyCode
from ruckig import InputParameter, OutputParameter, Result, Ruckig, ControlInterface
from ume.redis_client import RedisClient

def main(
    redis_host: str = "localhost",
    redis_port: int = 6379,
    name: str = "hexfellow_base_controller",
    history_length_seconds: int = 30,
    model_inference_worker_name: str = "model_inference",
    chunk_renew_every_s: float = 2.0,
    stitch_duration: float = 0.0
):
    client = RedisClient(host=redis_host, port=redis_port)
    xbox = XboxController()
    control_mode = "mit"  # Change to "mit" for MIT control mode
    with \
        canopen.Network().connect(channel='can0', bustype='socketcan', fd=True) as network_L, \
        canopen.Network().connect(channel='can1', bustype='socketcan', fd=True) as network_R, \
        HexFellowChain(network_L, node_ids=[2, 1, 4, 3], mode=control_mode) as hex_chain_L, \
        HexFellowChain(network_R, node_ids=[2, 1, 4, 3], mode=control_mode) as hex_chain_R:

        controller = HexFellowBaseController(hex_chain_L, hex_chain_R)
        
        DOF = 3
        CONTROL_FREQUENCY = 1000
        CONTROL_PERIOD = 1 / CONTROL_FREQUENCY
        MAX_VEL = np.ones(DOF) * 0.5
        MAX_ACC = np.ones(DOF) * 0.8
        otg = Ruckig(DOF, CONTROL_PERIOD)
        otg_input = InputParameter(DOF)
        otg_output = OutputParameter(DOF)
        otg_input.max_velocity = MAX_VEL
        otg_input.max_acceleration = MAX_ACC
        otg_input.control_interface = ControlInterface.Velocity
        last_desired_vel_xyt = np.zeros(DOF)
        
        max_redis_history_length = int(CONTROL_FREQUENCY * history_length_seconds)

        reg = FrequencyRegulator(CONTROL_FREQUENCY)  # 1000 Hz control loop
        
        eval_state = "idle"
        desired_base_velocity_xyt_interp = None
        
        with KeystrokeCounter() as key_counter:
            while True:
                
                # get current state
                t_now = time.time()
                actual_position_rad = controller.get_actual_position_rad()
                actual_velocity_radps = controller.get_actual_velocity_radps()
                
                data_batch = client.stream_get_batch(
                    {
                        f"{model_inference_worker_name}:action_timestamp": np.ndarray,
                        f"{model_inference_worker_name}:action_desired_base_velocity_xyt": np.ndarray
                    }
                )
                model_action_timestamp = data_batch[f"{model_inference_worker_name}:action_timestamp"]
                model_desired_base_velocity_xyt = data_batch[f"{model_inference_worker_name}:action_desired_base_velocity_xyt"]
                
                # handle keyboard input for state transitions
                for press_events in key_counter.get_press_events():
                    if press_events == KeyCode(char='`'):
                        if model_action_timestamp is not None:
                            eval_state = "evaluating"
                            desired_base_velocity_xyt_interp = get_interp1d(model_action_timestamp, model_desired_base_velocity_xyt)
                            print("Evaluating... Interpolating desired base velocity from model inference.")
                        else:
                            print("No model inference data received yet. Cannot start evaluating.")
                    elif press_events == KeyCode(char='s'):
                        eval_state = "idle"
                        desired_base_velocity_xyt_interp = None
                        print("Stopping. Returning to idle state.")
                
                if eval_state == "evaluating" and desired_base_velocity_xyt_interp is not None and t_now > desired_base_velocity_xyt_interp.x[0] + chunk_renew_every_s + stitch_duration:
                    # if we are evaluating and close to the end of the model predicted trajectory
                    # recompute the interpolator with latest model output
                    
                    last_interp_end_time = desired_base_velocity_xyt_interp.x[0] + chunk_renew_every_s + stitch_duration
                    last_interp_end_desired_vel_xyt = np.zeros(3)
                    # stitch_duration = 0.0
                    stitched_model_action_timestamp = np.concatenate([[last_interp_end_time], model_action_timestamp + stitch_duration])
                    stitched_model_desired_base_velocity_xyt = np.concatenate([[last_interp_end_desired_vel_xyt], model_desired_base_velocity_xyt], axis=0)
                    desired_base_velocity_xyt_interp = get_interp1d(stitched_model_action_timestamp, stitched_model_desired_base_velocity_xyt)

                controller.update_kinematics_model(reg.dt)
                actual_velocity_xyt = controller.pcw_kinematics.dx
                actual_position_xyt = controller.pcw_kinematics.x

                scale = MAX_VEL[0]  # Max speed scaling factor (0.5 means max 0.5 m/s)
                
                if eval_state == "idle":
                    desired_vel_x = -xbox.LeftJoystickY * scale
                    desired_vel_y = -xbox.LeftJoystickX * scale
                    desired_vel_theta = -xbox.RightJoystickX * scale  # Max angular speed scaling
                    print(f"{time.time():.4f} Desired Velocity (m/s, rad/s): ({desired_vel_x:.2f}, {desired_vel_y:.2f}, {desired_vel_theta:.2f})")
                    desired_vel_xyt = np.array([desired_vel_x, desired_vel_y, desired_vel_theta])
                elif eval_state == "evaluating":
                    desired_vel_xyt = desired_base_velocity_xyt_interp(t_now)
                    print(f"{time.time():.4f} Desired Velocity from Model (m/s, rad/s): ({desired_vel_xyt[0]:.2f}, {desired_vel_xyt[1]:.2f}, {desired_vel_xyt[2]:.2f})")
                else:
                    raise ValueError(f"Unknown eval_state: {eval_state}")
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
